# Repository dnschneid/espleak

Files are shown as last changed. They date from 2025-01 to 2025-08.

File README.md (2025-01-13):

# espleak

Whole-home leak detection and mitigation with ESPHome and magnetometers!

Inspired by https://github.com/tronikos/esphome-magnetometer-water-gas-meter/

Features:
 * Uses two QMC5883L sensors attached to your water meter to precisely monitor and report flow
 * Configurable to detect multiple thresholds of abnormal flow
 * Configurable to react to abnormal sensor behavior indicative of severely abnormal flow
 * Automatically signals an external valve to shut off water
 * Protection functionality operates entirely standalone
 * Automatic calibration of sensors
 * Sensor resiliency features for reliable long-term operation

## How do I use this?

See the [example](example) directory for inspiration on installation. Note that for performance, espleak *only* uses the
Z axis of the magnetometers.  That means it's critical to have the QMC5883L installed flat against the meter (which is
the easiest way to install it anyway).

Once configured, the ESP32 operates autonomously. The on-board LED glows brighter for higher flows. If abnormal flow is
detected, the LED will blink and the GPIO output will signal to a connected water controller (or valve actuator) to shut
off water. Pressing the on-board button (or using the API) will reset any error conditions and allow the water to be
turned on again.

Several functional entities are exposed via the API:
 * The current flow rate
 * The accumulated total water
 * Whether a threshold is being approached (leak imminent)
 * Whether a threshold has been exceeded (leak detected)
 * A button to clear detected leaks and allow water to be turned on again

In addition, there are several diagnostic entities:
 * The monitor that triggered the leak mitigation (e.g., which threshold was exceeded)
 * A running count of sensor errors detected and mitigated
 * The current sample rate of the sensors
 * A status indicator for sensor failure, which may require recalibration or physical attention to resolve
 * A button to trigger recalibration

There are some useful services too:
 * `disarm`: disarms the leak detectors for the specified number of seconds. Useful if you (or an automation) is about
   to activate something that suddenly pulls a lot of water, such as refilling a tank water heater or turning on a large
   irrigation system. Calling disarm with a duration of 0 will immediately re-arm.
 * `set_total`: resets the total to a chosen value (e.g. to match your water meter)

Finally, there are a few hidden entities that can be enabled as needed:
 * The on-board button status
 * A button to restart the sensors (normally this is done automatically upon sensor error)
 * A number input to simulate additional flow, for testing thresholds

espleak will self-calibrate when first installed, and whenever the recalibrate button is pressed. Ensure no water is
flowing when calibration is triggered. After 30 seconds you can run a small stream of water on a sink or flush a toilet
to complete calibration (or don't; calibration will advance whenever water next flows).

## How does it work?

The two sensors are installed at a 90-degree offset. Together they form a quadrature encoder for the spinning magnet
connected to the water sensor's nutator.  This nutator spins rapidly, signalling a tiny fraction of a gallon each time
it spins.

The ESP32 polls these sensors as quickly as possible. At calibration time, the detected sensor noise levels are used to
set the hysteresis level, and the accumulated min/max data from the sensors sets the threshold for positive and negative
state. The states of the two sensors are then quadrature decoded to detect forward and backwards spinning of the magnet.
The spins are counted over time to interpret the flow rate. This, along with the accumulated rotations, are exposed via
API as metrics.

On the ESP32, the flows are also compared against a set of thresholds. Exceeding the thresholds will advance a counter,
and once the allowed excursion time has elapsed, the ESP32 will assert a GPIO that signals an external water controller
(probably a valve actuator) to shut water off. The event is logged to the API and must be cleared either via a physical
button or via the API before the water controller is allowed to re-enable water.

In addition, if flow rate is so high that the rotations exceed the sample rate of the sensors, heuristics detect the
abnormal sensor data and will trigger the same mitigation mechanism.

See the yaml comments for more details on configuring the monitors.

To help with resiliency, the ESP32 can power cycle and reconfigure the sensors to recover from bus or sensor errors. At
the moment, this requires modified versions of the `i2c_bus` and `qmc5883l` components, which are hosted at
[dnschneid/esphome@i2creset](https://github.com/dnschneid/esphome/tree/i2creset) and pulled in by `espleak.yaml`.

## How do I test it?

Test the flow reporting by filling up a bucket in a fixture and timing how long it takes to fill up. The reported flow
during the fill should equal the volume of the bucket divided by the time it took to fill.

Test the flow-based leak response by enabling the flow simulator entity and increasing the flow until it is just below
the threshold of one of your entries. Then, turn on a fixture to push the flow over the limit and confirm the system
reacts after time has elapsed. You can shut off the fixture before time has elapsed to confirm that the timing resets.
Hitting the "clear leak" button will automatically zero out the flow simulator.

Testing the burst heuristics is more involved. The easiest way is to target a burst flow rate that can be quickly
achieved by something you control -- be it a garden hose nozzle, a washing machine, or even an irrigation system. Then,
increase the `sensor_update_interval_ms` setting until the flow rate is outside the measurable range of the sensors (see
the `flow_max` calculation). Once you've installed the updated image, you should be able to trigger the burst heuristics
by suddenly activating your flow source. You can try different update intervals to push the sensing into different
regions of operation. Remember to revert the update interval when you're done testing, otherwise your next shower will
be extremely short.

## Caveats?

Due to the 200Hz maximum sample rate, espleak may not suffice for larger homes. The exact thresholds are dependent on
what meter you have. For the Badger 25, for example, if you anticipate having >7.5 gallons/minute of normal water usage,
some of the detection features are diminished. Extreme flow mitigation won't be nearly as reliable if you expect >15
gallons/minute, and the system can't even correctly report flows above 30 gallons/minute, although it can still react to
abnormal flows beyond that. For a Badger 25, 2~3 baths is a reasonable limit. Larger homes may have larger meters,
though, so you should do the math.

You should understand how the system works and convince yourself that you have installed and configured all of the
requisite hardware and software correctly before relying on it to protect your property. You should test its behavior
regularly to confirm that the system is active and working, adjusting sensor positions or recalibrating as necessary.
You should regularly check that the water controller is functional and able to shut off water.

This software is provided as-is, without warranty of any kind. The author is not liable for any damages or inconveniences caused by the function or non-function of this software. See
LICENSE for more disclaimers.

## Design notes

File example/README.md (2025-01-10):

# Example installation

This is a high-level guide for an example espleak installation. You may need to adapt depending on your specific
situation; in particular the resistor pull-ups on I2C. This particular setup with the values on the schematic have been
tested successfully at 150KHz bus speeds with a 60ft CAT6 cable, but it should be able to go longer.

## Bill of materials

 * [Bulldog water valve actuator](https://www.econetshop.com/bulldog.html), with battery backup and outdoor kit (ODK-2)
 * If needed for extending the valve actuator cable: [PS/2 extension](https://www.amazon.com/dp/B092S5HY19)
   and [waterproof junction box](https://www.amazon.com/dp/B07TFSLLBY)
 * [2.5mm TS cable, right-angle](https://www.amazon.com/dp/B0D4Q8QTM7) for interfacing with the Bulldog controller
 * Breadboard, 2N3906 PNP transistor, optoisolator, several through-hole resistors, LED (see schematic)
 * [ESP32-POE-ISO-16MB-IND](https://www.olimex.com/Products/IoT/ESP32/ESP32-POE-ISO/)
 * Bulk direct-burial CAT6 cable
 * [PCA9515A I2C repeater module](https://www.amazon.com/dp/B0BG2BLKVJ) (2 total)
 * [QMC5883L modules](https://www.olimex.com/Products/Modules/Sensors/MOD-HMC5883L/) (2x)
 * Sensor waterproofing, e.g. [1" diameter 4:1 adhesive-lined heat shrink tubing](https://www.amazon.com/dp/B0B616X94M)

## Overview

The ESP32 board lives with the Bulldog controller and backup battery in the weatherproof box. An IO board provides the
interfacing between the ESP32 and the Bulldog controller (via an optoisolator and the 2.5mm TS cable), as well as an LED
for status. The IO board also provides the power switch and stronger pull-up resistors for the two sensors, which
connect via a single CAT6 cable.

Each sensor is attached directly to its own PCA9515A I2C repeater, which provides significantly higher drive strength,
allowing for faster speeds over longer distances than the QMC5883L is capable of by itself. The PCA9515A boards connect
to the CAT6 cable.

CAT6 cables have four sets of two twisted wires. Each sensor gets two twisted pairs. SDA and +3.3V are on one pair, SCL
and GND on the other. This works decently enough to mitigate noise issues thanks to the capacitors at either end. If
noise does cause failures in the sensing, the system can recover by resetting the sensors.

The pair of sensors with PCA9515A boards attached are enclosed in a single piece of heat shrink tubing for both
waterproofing and placement rigidity. The assembly is zip-tied to the water meter in the appropriate location.

## IO board

The IO board is pretty simple and can be built up on a breadboard or other prototyping aid.

IO board schematic

When wiring up the 2.5mm TS cable, think about how to provide some strain relief in case it gets yanked during
installation. The wires on audio cables tend to be very thin and fragile.

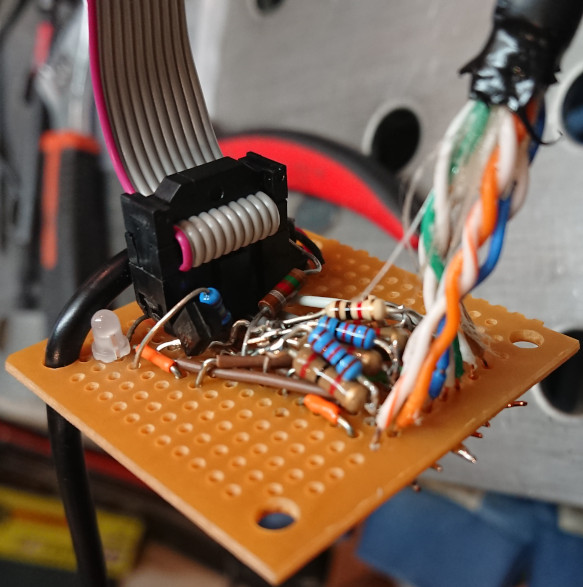
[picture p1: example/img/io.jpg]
Pretty janky IO board prototype


Note that if you are not using the PCA9515A, you should not have anything stronger than 2.2K total pull-up resistance on
the I2C lines. The QMC5883L by itself is only rated for 1mA of drive strength (whereas the PCA9515A can do 6mA). This
will limit you to 12ft or so of CAT6.

## Cabling

Running the cable between the controller box and the water meter can be tricky and a fair bit of work. You may need to
dig a trench in your yard to bury the cable. Aim for at least 3" deep; if you have professionally-installed landscape
wiring already, you can use that as a reference for the proper depth. If you have to go under the sidewalk to get to
your meter, you may need to use a long cable drill bit to guide the cable through.

Leave enough extra cable on both ends to make it easier to work with, and in case wires break during installation.
Unless you're trying to do without the PCA9515A repeater, a few extra feet isn't going to make much of a difference.

Direct-burial CAT6 has grease on the inside to protect from water ingress; this stuff is gross and makes a mess while
you're trying to fiddle with the individual wires, but is harmless to you and electronics.

## Sensor modules

The most sensitive part of the QMC5883L module is the top of the IC itself. This is the Z axis, and the goal is to get
that flat up against and as close to the spinning magnet as possible. The PCA9515A module should be mounted on the
backside of the QMC5883L module, so that it's not between the QMC5883L IC and the meter.

Conveniently, the QMC5883L module's thru-hole header matches the pinout of the PCA9515A module. You can put a row of 4x
0.1" pins between the module and the PCA9515A as in the picture below. The two boards can be directly soldered to the
pins at an angle so that when squeezed together they form a strong triangle. The CAT6 cable can then be soldered
directly into the other side of the PCA9515A module. The module conveniently passes through VCC0 and GND, and there's no
need to connect VCC1 or EN to anything.

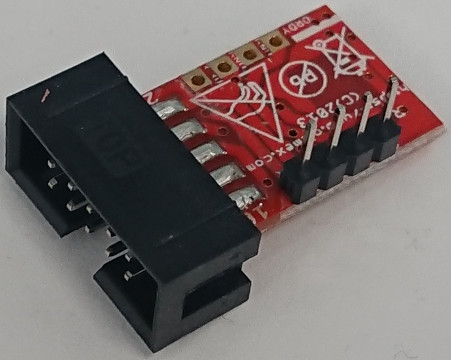
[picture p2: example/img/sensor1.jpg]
QMC5883L oriented with pins
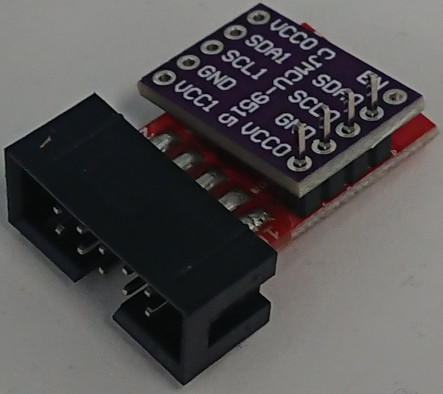
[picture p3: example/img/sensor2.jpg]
QMC5883L with PCA9515A ready to solder
 

Alternatively, you can cut the SDA/SCL traces to the 10-pin header on the QMC5883L and wire between the connector pins
and the PCA9515A module. Then you can cut a UEXT cable in half and splice the wires to the CAT6 cable. This is a little
more fiddly but allows the module to be detached. While being able to replace the module may be nice, it's mechanically
less robust than the direct connection and probably not worth the effort.

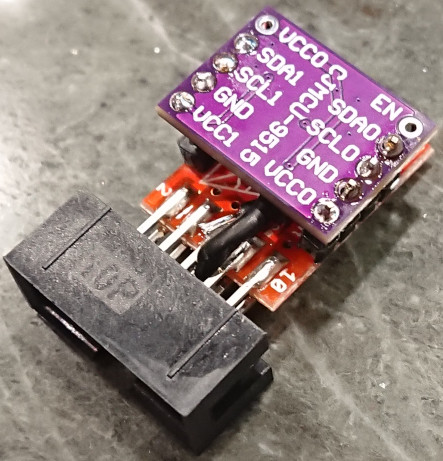
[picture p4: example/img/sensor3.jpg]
QMC5883L with traces cut, PCA9515A attached, and wires to pins


## Mounting the sensors

The sensors should be spaced apart so that when they wrap around the base of the meter (the metal portion, not the upper
dial body portion), they are 90 degrees apart from each other. CAT6 is pretty stiff so you'll need to fiddle with the
wires a bit to get the sensors the right distance apart. Once you have established that gap, run the modules and the
CAT6 into a continuous length of heatshrink tubing. The tubing should extend past the modules and separated wires on
both sides so that when you shrink it with a heat gun, it completely closes up on itself on one side, and tightly
encloses the CAT6 cable on the other, forming a decent seal. Shrink the tubing on the far side of the sensor (the
PCA9515A side) before shrinking it on the sensor side, to reduce the thickness of material on the sensor side.

With the module fully weather-sealed, wrap the resulting stiff noodle around the base of the meter. This is
meter-dependent, but you're basically aiming for the part closest to the pipe itself that you can still wrap around
uninterrupted. Somewhere around there is the magnet that produces the signal the sensors need to read. Once you've
gotten them in approximately the right place, hold them there with some zipties. The stiffness of the heat shrink helps
here; in this example we only needed two zip ties to hold everything firmly together. You can use pliers to pull the zip
ties extra tight.

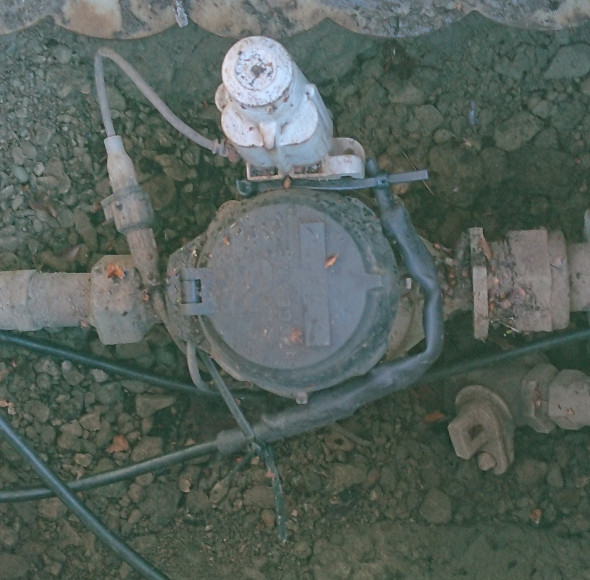
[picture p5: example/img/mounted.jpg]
2x sensors mounted to the water meter body


## Controller box

The ESP32, IO board, Bulldog controller, and battery can all fit comfortably in the waterproof box. Note that EcoNet
Controls provides the controller and battery already nicely mounted inside the box with the ODK-2 purchase option.

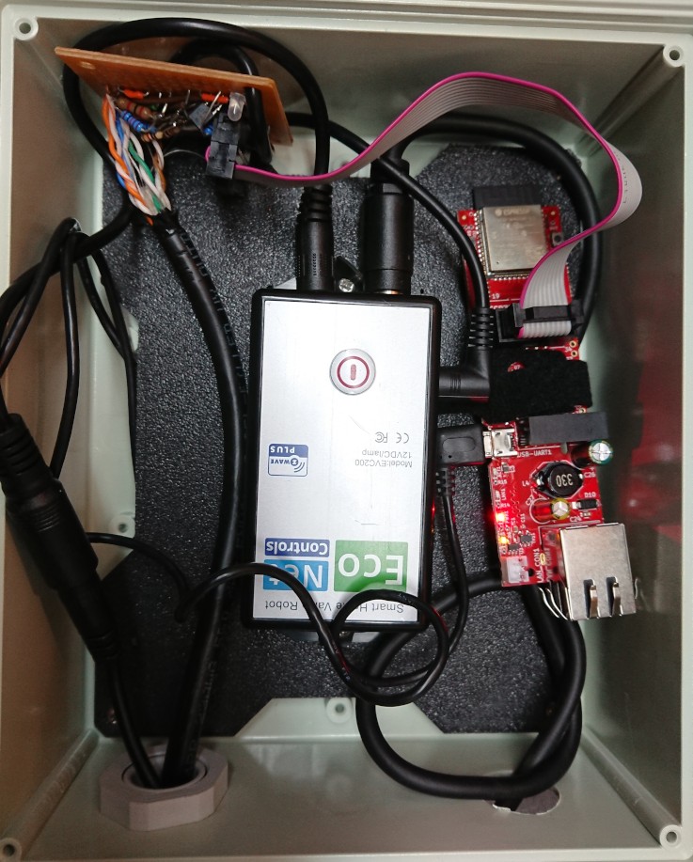
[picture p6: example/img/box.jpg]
Controller box configuration


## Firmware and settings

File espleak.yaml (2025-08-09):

# Copyright (C) 2025 David Schneider
#
# Licensed under the Apache License, Version 2.0 (the "License");
# you may not use this file except in compliance with the License.
# You may obtain a copy of the License at
#
#         http://www.apache.org/licenses/LICENSE-2.0
#
# Unless required by applicable law or agreed to in writing, software
# distributed under the License is distributed on an "AS IS" BASIS,
# WITHOUT WARRANTIES OR CONDITIONS OF ANY KIND, either express or implied.
# See the License for the specific language governing permissions and
# limitations under the License.

substitutions:
  # Critical configuration
  i2c_a_scl: GPIO16  # sensor A I2C clock
  i2c_a_sda: GPIO13  # sensor A I2C data
  i2c_b_scl: GPIO14  # sensor B I2C clock
  i2c_b_sda: GPIO15  # sensor B I2C data
  leak_out:  GPIO5   # leak detected output, active-high output
  qmc_off:   GPIO4   # sensor power-down signal, active-high output
  led:       GPIO2   # status LED, active-high output
  button:    GPIO34  # on-device clear/reset button, active-low input
  volume_per_quarter_rotation: '0.25/198.334'  # From https://www.instrumart.com/assets/badger-er10_manual.pdf
  sensor_update_interval_ms: '5'  # 5 (200Hz), unless I2C can't keep up. Increasing reduces maximum flow rate
  i2c_bus_frequency: '150khz'  # Recommended at least 100khz to maintain 200Hz sampling consistently
  reverse_flow: 'false'  # Flip this if your sensor order results in negative flow in normal conditions
  flow_interval_s: '1'  # Increasing this allows for reporting tinier flows, but averages out short spikes

  # Cosmetic configuration
  flow_report_interval_s: '10'  # Increasing this beyond ${flow_interval_s} averages the data sent to HomeAssistant
  volume_unit: 'gal'  # Volume units

  # Functional/informative; DO NOT EDIT
  flow_epsilon: '${volume_per_quarter_rotation}*60/(${flow_interval_s})'  # The minimum reportable flow rate
  flow_max: '${volume_per_quarter_rotation}*120000/(${sensor_update_interval_ms})'  # The maximum reportable flow rate

  # flowmon: performs leak detection by monitoring flow rate over time
  # multiple monitors allow for faster response to higher flow rates
  # negative flow monitors react to an upstream leak, or aliasing from a high-flow pipe burst
  # Configure the monitors using pairs of flow threshold and allowed duration:
  #   threshold: maximum allowed flow in volume_units; beyond this, the timer will count down.
  #              can be negative. zero means any non-zero flow, positive *or* negative.
  #   duration: the number of seconds to allow a flow before triggering a leak. set to 0 to trigger instantly.
  # Set the flowmon_config variable with comma-separated pairs of threshold,duration. /* you can add C-style comments */
  # a leak warning will be issued in one of the following conditions:
  #   if the duration is at least flowmon_warn_s: less than flowmon_warn_s or flowmon_warn_s_factor of the time left
  #   if the duration is less than flowmon_warn_s: within flowmon_warn_thresh_factor of the flow threshold
  # To avoid false-positives, negative flows are ignored if the sample rate is below sample_rate_safety_factor of normal
  # To avoid false-negatives, monitors are only reset if the sample rate is above sample_rate_safety_factor of normal
  # The minimum flow rate detectable is ${flow_epsilon}, but natural variations of municipal water pressure as well as
  #   the expansion effect of tank water heaters will cause a small amount of flow in either direction.
  # Example flowmon strategy for a 2ba:
  #   Gather data:
  #   * time how long it takes a toilet to refill
  #   * turn on both showers and get the peak water usage with just the showers
  #   set the following monitors:
  #   0) 1.5x both showers for more than 5 seconds
  #   1) usage beyond both showers for more than a toilet refill period
  #   2) a single shower for more than an hour
  #   3) any flow for more than 3 hours
  #   4) a significant negative water flow for any amount of time
  # As a safety check, if there are an odd number of values in the config,
  #   you will get a compile-time error: "size of array 't' is negative"
  flowmon_config: '
    7.5, 5,   /* 1.5x all showers */
    5, 180,   /* beyond all showers for more than a toilet refill period */
    2, 3600,  /* one shower for more than an hour */
    0, 10800, /* any flow for more than 3 hours */
    -4*${flow_epsilon}, 0,  /* a significant negative water flow */
    '
  flowmon_warn_s: '60'
  flowmon_warn_s_factor: '0.05'
  flowmon_warn_thresh_factor: '0.9'
  sample_rate_safety_factor: '0.95'
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

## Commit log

2025-01-08 Add example, with schematic
    [ioboard.kicad_sch]
2025-01-08 Render schematic in readme
2025-01-09 Add note about z-axis
2025-01-09 Note on 2.5mm
2025-01-10 Mention EN pin and include photo of IO board
2025-01-10 flowmon: include flow in trigger log
2025-01-25 Stop min/max accumulation after 1000 rotation ticks
    Print out calibration min/max once done
    Otherwise over time if there's ever a broken sample or something very
    magnetic goes by the meter, calibration will get thrown off.
    [espleak.yaml]
2025-06-01 Fix units for sample_rate
    HomeAssistant is case-sensitive
    [espleak.yaml]
2025-08-09 Sample noise for hysteresis a bit longer
    [espleak.yaml]
